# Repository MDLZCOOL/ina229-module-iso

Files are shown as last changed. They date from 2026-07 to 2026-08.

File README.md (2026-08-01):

# 电压电流模块（全隔离版）

## 简介

采用ina229前端+cs32l010f8u6单片机做的信号供电全隔离的电压电流模组，采用串口MODBUS输出，支持0-85V电压测量。



至于为什么是cs32l010f8u6，最近偶然得到几百片这个mcu，想办法用掉吧~

## 使用须知

- 支持测量的电压范围是0-85V
- 支持测量的最大电流与采样电阻有关，计算公式为`I_MAX ≤ 0.16384 / R_SHUNT`，其中R_SHUNT单位为欧姆，I单位安培
- 用户需要同时接入3.3V和5V电平，其中丝印3.3V的位置可以接入其他电平，作为串口RXTX的输出电平，5V位置只能接入5V
- “全隔离”指信号与供电全隔离，如果用户供电或信号的地与被测电流电压信号的地导通，则不隔离，但是仍可正常使用

## 上位机

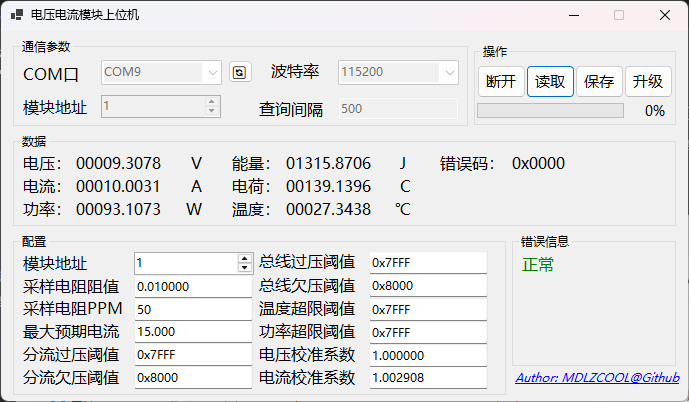
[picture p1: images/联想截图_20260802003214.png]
联想截图_20260802003214


- 上位机可以用于更改模块MODBUS地址、采样电阻信息、最大预期电流、校准系数
- 需要注意的是，最大预期电流公式见“使用须知”，并不是无限大的
- 所以用户更改采样电阻以适配不同精度，不同量程后，需要手动更新采样电阻信息，也可能需要重新设置校准系数
- 校准系数 = 实测值 ÷ 上位机显示值
- 上位机可以直接进行固件升级，连接好后，点击“升级”，选择新的bin文件即可进行升级，升级不会导致配置信息丢失。如果升级失败，可以“按住按键”并重新上电后重试

## Modbus 寄存器表

### 通信参数

| 项目 | 值 |
| --- | --- |
| 物理接口 | 串口（UART，隔离输出） |
| 协议 | Modbus RTU |
| 波特率 | 115200 bps |
| 数据位 / 校验 / 停止位 | 8 / None / 1 |
| 从机地址 | 可配置，默认 1 |
| 实现的功能码 | `0x03` 读保持寄存器、`0x06` 写单个寄存器、`0x10` 写多个寄存器 |

### 数据格式说明

- 浮点数（float）：IEEE-754 单精度，占用 2 个连续寄存器高位字在前（Big-Endian）。即地址 N 存高 16 位、地址 N+1 存低 16 位，每个寄存器内部字节大端。
- 整型（uint16）：占用 1 个寄存器，大端。
- 测量数据区为只读（RO），用于获取测量数据。
- 配置参数区为可读写（RW）：修改后先存于 RAM，需向 `0x0110` 写入保存指令才会写入 Flash。

### 保持寄存器 — 测量数据（只读）

| 地址(hex) | 地址(dec) | 寄存器范围 | 名称 | 类型(寄存器数) | 单位 | 说明 |
| --- | --- | --- | --- | --- | ---- | --- |
| 0x0000 | 0 | 0x0000–0x0001 | Voltage（电压） | float (2) | V | 总线电压 |
| 0x0002 | 2 | 0x0002–0x0003 | Current（电流） | float (2) | A | 电流 |
| 0x0004 | 4 | 0x0004–0x0005 | Power（功率） | float (2) | W | 功率 |
| 0x0006 | 6 | 0x0006–0x0007 | Charge（电荷量） | float (2) | C | 累计电荷量 |
| 0x0008 | 8 | 0x0008–0x0009 | Temperature（温度）  | float (2) | °C | 内部温度 |
| 0x000A | 10 | 0x000A–0x000B | Energy（能量） | float (2) | J | 累计能量，1 Wh = 3600 J |
| 0x000C | 12 | 0x000C | Error Code（错误码） | uint16 (1) | — | INA229 诊断/告警位域，见第 5 节 |

### 保持寄存器 — 配置参数（可读写）

| 地址(hex) | 地址(dec) | 寄存器范围 | 名称 | 类型(寄存器数) | 单位 | 默认值 | 说明 |
| --- | --- | --- | --- | --- | --- | --- | --- |
| 0x0100 | 256 | 0x0100 | ModbusAddr | uint16 (1) | — | 1 | 本机 Modbus 从机地址 |
| 0x0101 | 257 | 0x0101–0x0102 | RshuntOhm  | float (2) | Ω | 0.01 | 采样电阻值 R_SHUNT；修改后需用 0x0103 配合标定为新量程 |
| 0x0103 | 259 | 0x0103–0x0104 | IexpMax | float (2) | A | 15.0 | 最大预期电流 I_MAX；约束：`I_MAX ≤ 0.16384 / R_SHUNT`  |
| 0x0105 | 261 | 0x0105 | ShuntOVTｈ | uint16 (1) | — | 0x7FFF | 分流过压阈值（SOVL） |
| 0x0106 | 262 | 0x0106 | ShuntUVTh  | uint16 (1) | — | 0x8000 | 分流欠压阈值（SUVL） |
| 0x0107 | 263 | 0x0107 | BusOVTｈ | uint16 (1) | — | 0x7FFF | 总线过压阈值（BOVL） |
| 0x0108 | 264 | 0x0108 | BusUVTh | uint16 (1) | — | 0x8000 | 总线欠压阈值（BUVL） |
| 0x0109 | 265 | 0x0109 | TempOLTh | uint16 (1) | — | 0x7FFF | 温度超限阈值（TEMP_LIMIT） |
| 0x010A | 266 | 0x010A | PowerOLTh  | uint16 (1) | — | 0x7FFF | 功率超限阈值（PWR_LIMIT） |
| 0x010B | 267 | 0x010B–0x010C | VoltageK | float (2) | — | 1.0 | 电压校准系数 = `实测值 ÷ 显示值` |
| 0x010D | 269 | 0x010D–0x010E | CurrentK | float (2) | — | 1.0 | 电流校准系数 = `实测值 ÷ 显示值` |
| 0x010F | 271 | 0x010F | RshuntPPM  | uint16 (1) | ppm/°C | 50 | 采样电阻温度系数 |
| 0x0110 | 272 | 0x0110 | SaveCmd | uint16 (1) | — | 0 | 写命令：写入 `0x4B56` 将当前配置保存到 Flash |
| 0x0111 | 273 | 0x0111 | BootCmd | uint16 (1) | — | 0 | 写命令：写入 `0x4B4F` 重启进入固件升级模式 |

### 错误码（Error Code，0x000C）位定义

| Bit  | 宏 / 名称 | 含义 |
| ---- | --- | --- |
| 0 | MEMSTAT | 存储器校验错误 |
| 1 | CNVRF | 转换完成标志 |
| 2 | POL | 功率超限 |
| 3 | BUSUL | 总线欠压 |
| 4 | BUSOL | 总线过压 |
| 5 | SHNTUL | 分流欠压 |
| 6 | SHNTOL | 分流过压 |
| 7 | TMPOL | 温度超限 |
| 8 | OFFLINE | 芯片离线 |
| 9 | MATHOF | 数学计算溢出 |
| 10 | CHARGEOF  | 电荷寄存器溢出 |
| 11 | ENERGYOF  | 能量寄存器溢出 |

### 使用要点

- 读实时数据：用功能码 `0x03` 读取 0x0000–0x000C。
- 改配置并保存：先写 0x0100–0x010F 中目标寄存器，再向 0x0110 写 `0x4B56` 保存。
- 固件升级：向 0x0111 写 `0x4B4F` 进入升级模式，再用 YMODEM 方式烧录新 bin。
- 校准：`校准系数 = 实测值 ÷ 上位机显示值`，写入电压电流校准系数后保存。
- 量程约束：更换采样电阻后需重设采样电阻信息与最大预期电流，并满足 `I_MAX ≤ 0.16384 / R_SHUNT`，必要时重新校准系数。

## 目录结构

- [./Hardware](Hardware)下为硬件设计，使用Kicad 8.0以上版本打开
- [./Firmware](Firmware)下为编译好的固件
- [./Software](Software)下为mcu源码
- [./Upper](Upper)下为上位机源码
- [./Document](Document)下为mcu的ds和pack

## Changelog

20260713更新：初始化仓库。硬件完成，软件还没写，已送去jlc打样pcb+smt。。希望这个究极灵车mcu不要翻车了

20260801更新：V1.0，完成上位机，上位机实现了数据测量、参数修改、固件更新。完成下位机Application+Bootloader，实现modbus通信，传感器读取，参数保存，固件更新。

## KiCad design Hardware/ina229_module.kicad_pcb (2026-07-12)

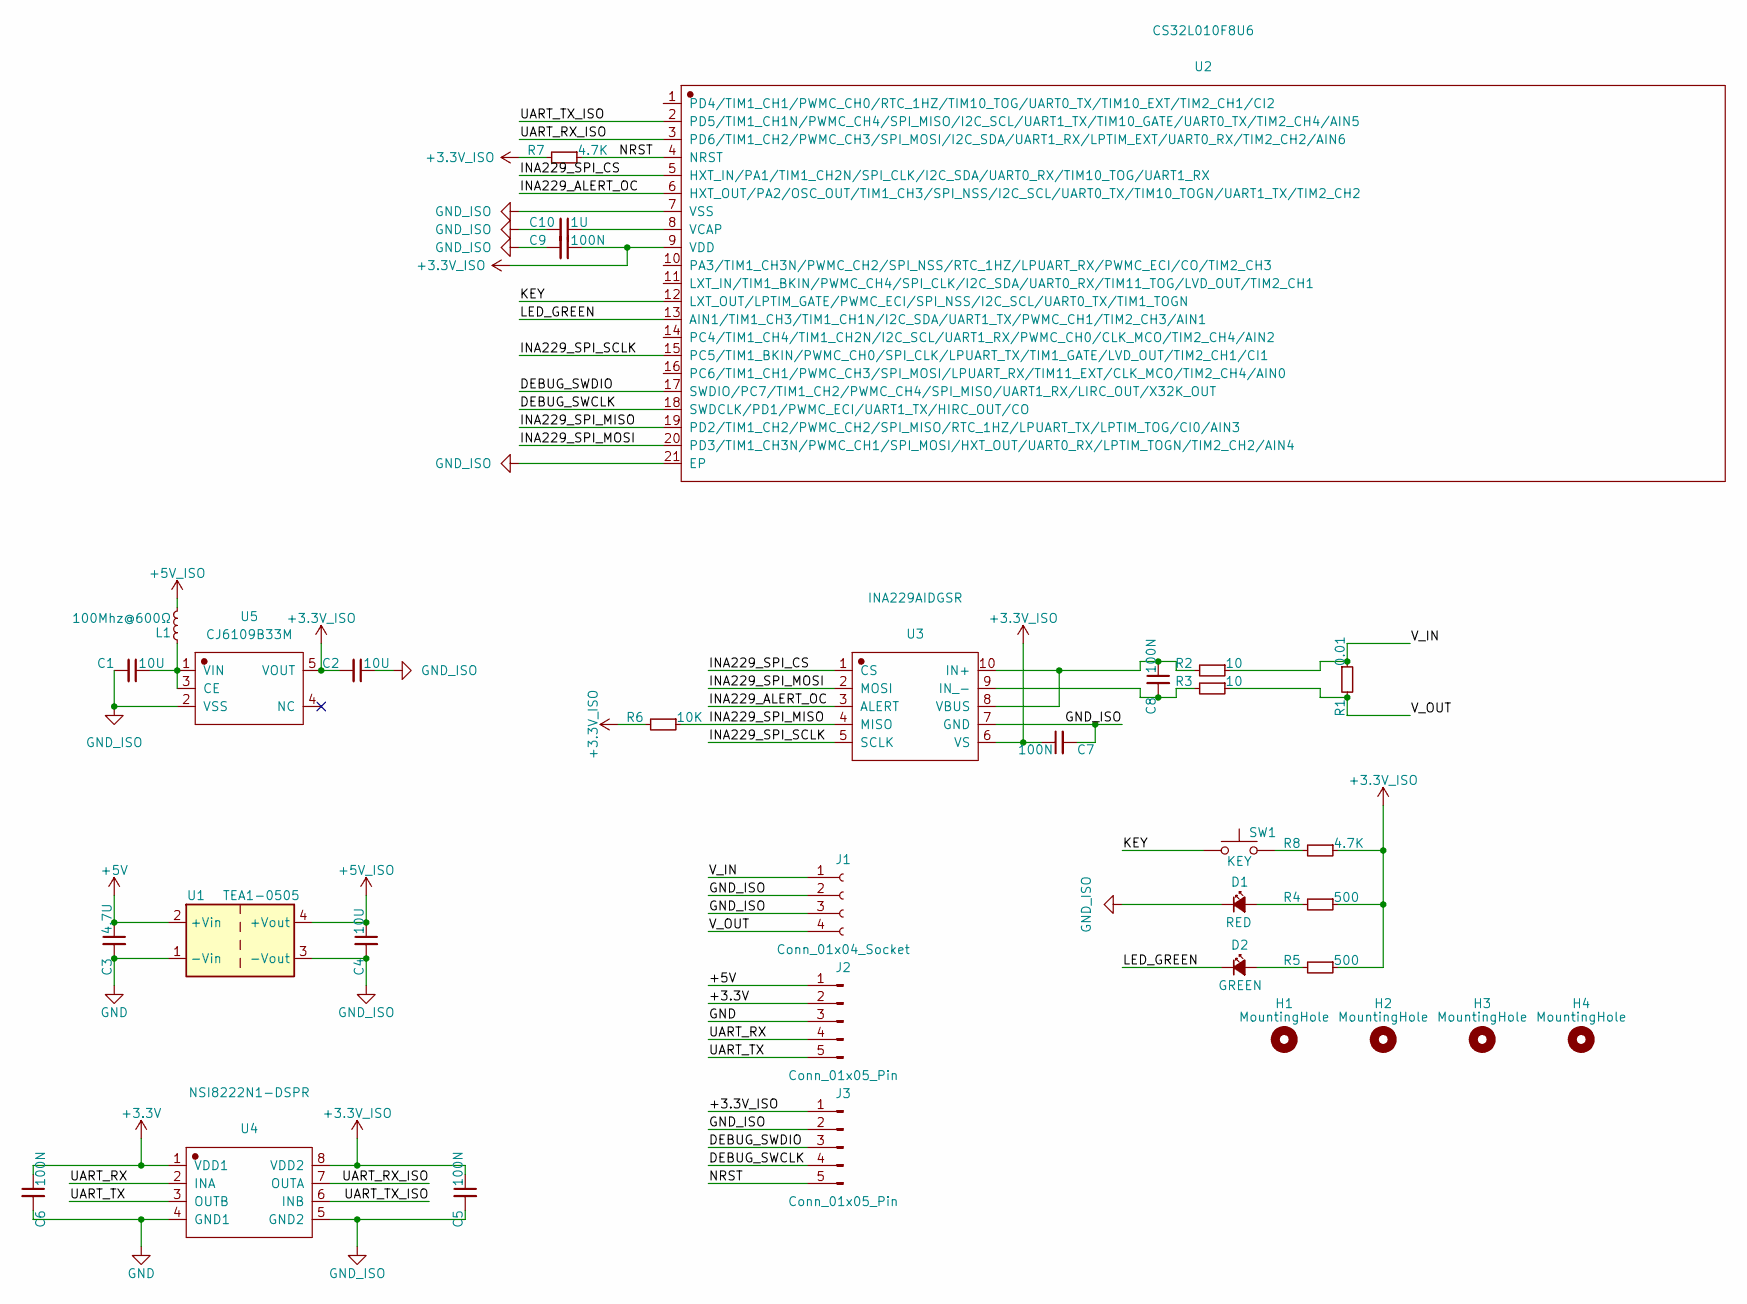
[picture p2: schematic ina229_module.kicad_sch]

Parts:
C1, C2, C4: 10U; C_0603_1608Metric_Pad1.08x0.95mm_HandSolder
C3: 4.7U; C_0603_1608Metric_Pad1.08x0.95mm_HandSolder
C5, C6, C7, C8, C9: 100N; C_0603_1608Metric_Pad1.08x0.95mm_HandSolder
C10: 1U; C_0603_1608Metric_Pad1.08x0.95mm_HandSolder
D1: RED; LED_0603_1608Metric_Pad1.05x0.95mm_HandSolder
D2: GREEN; LED_0603_1608Metric_Pad1.05x0.95mm_HandSolder
H1, H2, H3, H4: MountingHole; MountingHole_3.2mm_M3_ISO7380
J1: Conn_01x04_Socket; TerminalBlock_Phoenix_MKDS-1,5-4-5.08_1x04_P5.08mm_Horizont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
J2: Conn_01x05_Pin; JST_XH_B5B-XH-A_1x05_P2.50mm_Vertical
J3: Conn_01x05_Pin; PinHeader_1x05_P2.54mm_Vertical
L1: 100Mhz@600Ω; L_0603_1608Metric_Pad1.05x0.95mm_HandSolder
R1: 0.01; R_2512_6332Metric_Pad1.40x3.35mm_HandSolder
R2, R3: 10; R_0603_1608Metric_Pad0.98x0.95mm_HandSolder
R4, R5: 500; R_0603_1608Metric_Pad0.98x0.95mm_HandSolder
R6: 10K; R_0603_1608Metric_Pad0.98x0.95mm_HandSolder
R7, R8: 4.7K; R_0603_1608Metric_Pad0.98x0.95mm_HandSolder
SW1: KEY; SW_SPST_B3U-1000P
U1: TEA1-0505; Converter_DCDC_TRACO_TEA1-xxxx_THT
U2: CS32L010F8U6; WFQFN-20_L3.0-W3.0-P0.40-TL-EP1.7
U3: INA229AIDGSR; VSSOP-10_L3.0-W3.0-P0.50-LS4.9-BL
U4: NSI8222N1-DSPR; SOP-8_L4.9-W3.9-P1.27-LS6.0-BL
U5: CJ6109B33M; SOT-23-5_L2.9-W1.6-P0.95-LS2.8-BR

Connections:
+3.3V: C6.1, J2.2, U4.1 (VDD1)
+3.3V_ISO: C2.2, C5.1, C7.1, C9.1, J3.1, R4.1, R5.1, R6.2, R7.2, R8.1, U2.9 (VDD), U3.6 (VS), U4.8 (VDD2), U5.5 (VOUT)
+5V: C3.1, J2.1, U1.2 (+Vin)
+5V_ISO: C4.1, L1.2, U1.4 (+Vout)
/DEBUG_SWCLK: J3.4, U2.18 (SWDCLK/PD1/PWMC_ECI/UART1_TX/HIRC_OUT/CO)
/DEBUG_SWDIO: J3.3, U2.17 (SWDIO/PC7/TIM1_CH2/PWMC_CH4/SPI_MISO/UA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)
/INA229_ALERT_OC: U2.6 (HXT_OUT/PA2/OSC_OUT/TIM1_CH3/SPI_NSS/I2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), U3.3 (ALERT)
/INA229_SPI_CS: U2.5 (HXT_IN/PA1/TIM1_CH2N/SPI_CLK/I2C_SDA/UA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), U3.1 (CS)
/INA229_SPI_MISO: R6.1, U2.19 (PD2/TIM1_CH2/PWMC_CH2/SPI_MISO/RTC_1HZ/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), U3.4 (MISO)
/INA229_SPI_MOSI: U2.20 (PD3/TIM1_CH3N/PWMC_CH1/SPI_MOSI/HXT_OUT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), U3.2 (MOSI)
/INA229_SPI_SCLK: U2.15 (PC5/TIM1_BKIN/PWMC_CH0/SPI_CLK/LPUART_T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), U3.5 (SCLK)
/KEY: SW1.1, U2.12 (LXT_OUT/LPTIM_GATE/PWMC_ECI/SPI_NSS/I2C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)
/LED_GREEN: D2.1 (K), U2.13 (AIN1/TIM1_CH3/TIM1_CH1N/I2C_SDA/UART1_T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)
/NRST: J3.5, R7.1, U2.4 (NRST)
/UART_RX: J2.4, U4.2 (INA)
/UART_RX_ISO: U2.3 (PD6/TIM1_CH2/PWMC_CH3/SPI_MOSI/I2C_SDA/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), U4.7 (OUTA)
/UART_TX: J2.5, U4.3 (OUTB)
/UART_TX_ISO: U2.2 (PD5/TIM1_CH1N/PWMC_CH4/SPI_MISO/I2C_SCL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), U4.6 (INB)
/V_IN: J1.1, R1.1, R2.1
/V_OUT: J1.4, R1.2, R3.1
GND: C3.2, C6.2, J2.3, U1.1 (-Vin), U4.4 (GND1)
GND_ISO: C1.2, C2.1, C4.2, C5.2, C7.2, C9.2, C10.2, D1.1 (K), J1.2, J1.3, J3.2, U1.3 (-Vout), U2.7 (VSS), U2.21 (EP), U3.7 (GND), U4.5 (GND2), U5.2 (VSS)
unnamed: D1.2 (A), R4.2
unnamed: D2.2 (A), R5.2
unnamed: R8.2, SW1.2
unnamed: C10.1, U2.8 (VCAP)
unnamed: C8.1, R2.2, U3.8 (VBUS), U3.10 (IN+)
unnamed: C8.2, R3.2, U3.9 (IN_-)
unnamed: C1.1, L1.1, U5.1 (VIN), U5.3 (CE)

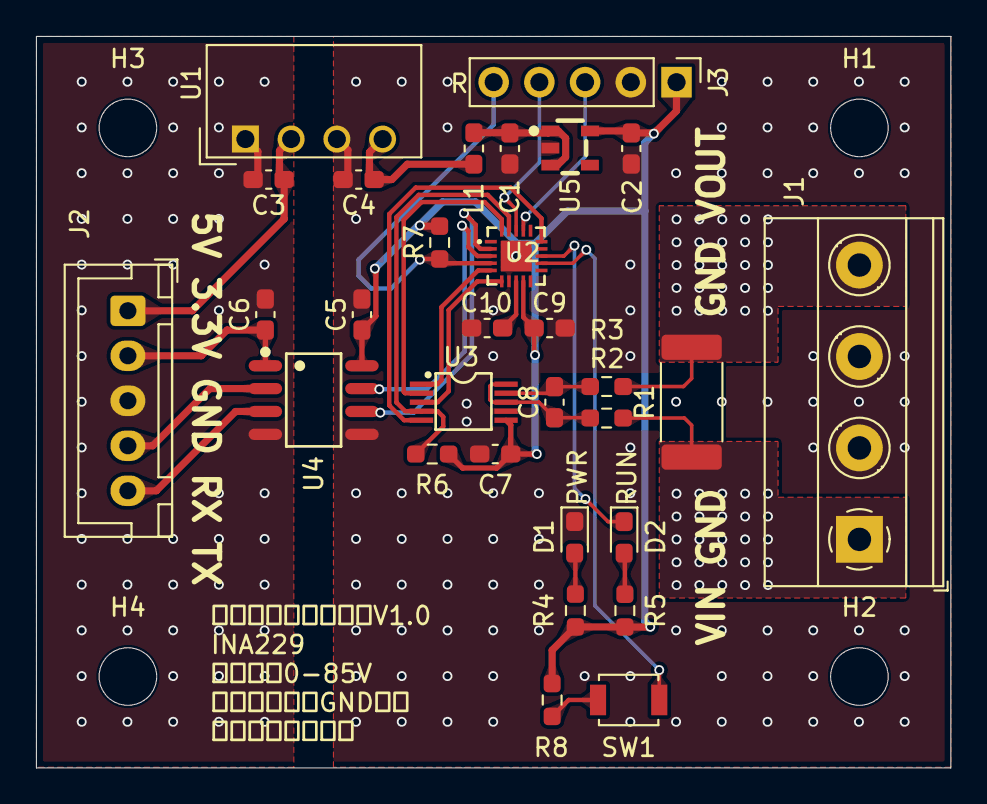
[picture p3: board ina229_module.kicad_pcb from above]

Board: 2 copper layers, 50.8 x 40.6 mm, 34 parts (0 on the bottom side), 29 nets.

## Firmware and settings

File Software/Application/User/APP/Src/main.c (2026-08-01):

/*
 * SPDX-FileCopyrightText: 2026 MDLZCOOL <mdlzcool@foxmail.com>
 *
 * SPDX-License-Identifier: Apache-2.0
 */

#include "main.h"

#include "app_kv.h"
#include "app_modbus.h"
#include "bsp_ina229.h"
#include "bsp_led.h"
#include "bsp_uart_fifo.h"
#include "perf_counter.h"
#include "soft_timer.h"

ina229_data_t g_ina229_data_inst;

CONFIG_T g_config;
int g_config_flash_valid = 0;

/* 加载默认值 */
static void config_load_defaults(void) {
  g_config.modbus_addr = CFG_DEFAULT_MODBUS_ADDR;
  g_config.rshunt_ohm = CFG_DEFAULT_RSHUNT_OHM;
  g_config.iexp_max = CFG_DEFAULT_IEXP_MAX;
  g_config.shunt_over_voltage_th = CFG_DEFAULT_SHUNT_OVER_VOLTAGE_TH;
  g_config.shunt_under_voltage_th = CFG_DEFAULT_SHUNT_UNDER_VOLTAGE_TH;
  g_config.bus_over_voltage_th = CFG_DEFAULT_BUS_OVER_VOLTAGE_TH;
  g_config.bus_under_voltage_th = CFG_DEFAULT_BUS_UNDER_VOLTAGE_TH;
  g_config.temp_over_limit_th = CFG_DEFAULT_TEMP_OVER_LIMIT_TH;
  g_config.power_over_limit_th = CFG_DEFAULT_POWER_OVER_LIMIT_TH;
  g_config.voltage_k = CFG_DEFAULT_VOLTAGE_K;
  g_config.current_k = CFG_DEFAULT_CURRENT_K;
  g_config.rshunt_ppm = CFG_DEFAULT_RSHUNT_PPM;
}

static void config_load_from_flash(void) {
  int ok = 0;
  ok += (app_KV_GetInt("1", &g_config.modbus_addr) == KV_OK);
  ok += (app_KV_GetFloat("2", &g_config.rshunt_ohm) == KV_OK);
  ok += (app_KV_GetFloat("3", &g_config.iexp_max) == KV_OK);
  ok += (app_KV_GetUint16("4", &g_config.shunt_over_voltage_th) == KV_OK);
  ok += (app_KV_GetUint16("5", &g_config.shunt_under_voltage_th) == KV_OK);
  ok += (app_KV_GetUint16("6", &g_config.bus_over_voltage_th) == KV_OK);
  ok += (app_KV_GetUint16("7", &g_config.bus_under_voltage_th) == KV_OK);
  ok += (app_KV_GetUint16("8", &g_config.temp_over_limit_th) == KV_OK);
  ok += (app_KV_GetUint16("9", &g_config.power_over_limit_th) == KV_OK);
  ok += (app_KV_GetFloat("10", &g_config.voltage_k) == KV_OK);
  ok += (app_KV_GetFloat("11", &g_config.current_k) == KV_OK);
  ok += (app_KV_GetUint16("12", &g_config.rshunt_ppm) == KV_OK);

  /* 参数全部读到才算有效 */
  if (ok == 12) {
    g_config_flash_valid = 1;
    LOG_printf("Loaded from Flash.\r\n");
  } else {
    LOG_printf("Flash incomplete, using defaults.\r\n");
  }
}

/* 首次烧录写入默认值 */
static void config_save_defaults_to_flash(void) {
  app_KV_SetInt("1", g_config.modbus_addr);
  app_KV_SetFloat("2", g_config.rshunt_ohm);
  app_KV_SetFloat("3", g_config.iexp_max);
  app_KV_SetUint16("4", g_config.shunt_over_voltage_th);
  app_KV_SetUint16("5", g_config.shunt_under_voltage_th);
  app_KV_SetUint16("6", g_config.bus_over_voltage_th);
  app_KV_SetUint16("7", g_config.bus_under_voltage_th);
  app_KV_SetUint16("8", g_config.temp_over_limit_th);
  app_KV_SetUint16("9", g_config.power_over_limit_th);
  app_KV_SetFloat("10", g_config.voltage_k);
  app_KV_SetFloat("11", g_config.current_k);
  app_KV_SetUint16("12", g_config.rshunt_ppm);

  app_KV_Save();
  LOG_printf("Defaults saved to Flash.\r\n");
}

// 24M clock
void SystemClock_Config(void) {
  RCC_OscInitTypeDef RCC_OscInitStruct = {0};
  RCC_ClkInitTypeDef RCC_ClkInitStruct = {0};

  RCC_OscInitStruct.OscillatorType = RCC_OSCILLATORTYPE_HIRC;
  RCC_OscInitStruct.HIRCState = RCC_HIRC_ON;
  RCC_OscInitStruct.HIRCCalibrationValue = RCC_HIRCCALIBRATION_24M;

  if (HAL_RCC_OscConfig(&RCC_OscInitStruct) != HAL_OK) {
    Error_Handler();
  }

  RCC_ClkInitStruct.ClockType =
      RCC_CLOCKTYPE_HCLK | RCC_CLOCKTYPE_SYSCLK | RCC_CLOCKTYPE_PCLK;
  RCC_ClkInitStruct.SYSCLKSource = RCC_SYSCLKSOURCE_HIRC;
  RCC_ClkInitStruct.AHBCLKDivider = RCC_HCLK_DIV1;
  RCC_ClkInitStruct.APBCLKDivider = RCC_PCLK_DIV1;

  if (HAL_RCC_ClockConfig(&RCC_ClkInitStruct) != HAL_OK) {
    Error_Handler();
  }
}

#define APP_ADDR 0x00002000

int main(void) {
  /* 硬件复位后 PRIMASK=0；若从 Bootloader 跳转来，确保中断开启 */
  __enable_irq();

  HAL_Init();

  SystemClock_Config();

#if DEBUG_RTT
  SEGGER_RTT_Init();
#endif

  app_KV_Init();
  app_KV_List();

  config_load_defaults();

  config_load_from_flash();

  if (!g_config_flash_valid) {
    config_save_defaults_to_flash();
  }

  LOG_printf("modbus addr=%d\r\n", g_config.modbus_addr);
  LOG_printf("rshunt %d.%03d Ohm, Imax=%d.%03d A\r\n",
             FLOAT_INT(g_config.rshunt_ohm), FLOAT_FRAC3(g_config.rshunt_ohm),
             FLOAT_INT(g_config.iexp_max), FLOAT_FRAC3(g_config.iexp_max));

  bsp_InitLed();

  bsp_InitIna229(g_config.rshunt_ohm, g_config.iexp_max);

  INA229_SetShuntTemperatureCoefficient(g_config.rshunt_ppm);
  INA229_SetTemperatureCompensation(1);

  INA229_SetAverage(INA229_ADC_CONFIG_AVG_64);
  INA229_SetShuntOvervoltageTH(g_config.shunt_over_voltage_th);
  INA229_SetShuntUndervoltageTH(g_config.shunt_under_voltage_th);
  INA229_SetBusOvervoltageTH(g_config.bus_over_voltage_th);
  INA229_SetBusUndervoltageTH(g_config.bus_under_voltage_th);
  INA229_SetTemperatureOverLimitTH(g_config.temp_over_limit_th);
  INA229_SetPowerOverLimitTH(g_config.power_over_limit_th);

  bsp_InitUart();

  app_ModbusInit(g_config.modbus_addr);
  app_Modbus_ConfigInit();

  InitSoftTimer();
  StartSoftAutoTimer(0, 1);
  StartSoftAutoTimer(1, 10);
  StartSoftAutoTimer(2, 500);

  while (1) {
    if (CheckSoftTimer(0) == 1) {
      app_Modbus_Poll();
    }
    if (CheckSoftTimer(1) == 1) {
      int32_t cycle_used = 0;
      double t = INA229_GetShuntVoltage();
      // LOG_printf("%d.%06d V\r\n", FLOAT_INT(t), FLOAT_FRAC6(t));
      __cycleof__("", { cycle_used = _; }) {
        g_ina229_data_inst.voltage =
            INA229_GetBusVoltage() * g_config.voltage_k;
        g_ina229_data_inst.current = INA229_GetCurrent() * g_config.current_k;
        g_ina229_data_inst.temp = INA229_GetTemperature();
        g_ina229_data_inst.charge = INA229_GetCharge();
        g_ina229_data_inst.power =
            INA229_GetPower() * g_config.current_k * g_config.voltage_k;
        g_ina229_data_inst.energy = INA229_GetEnergy();
        g_ina229_data_inst.err_code = INA229_Get_ErrorCode();
        Modbus_Update_INA229(&g_ina229_data_inst);
      }

      // LOG_printf("Task: %d cycles, approx %d us\r\n", cycle_used, cycle_used
      // / 24);
    }
    if (CheckSoftTimer(2) == 1) {
      bsp_LedToggle(1);
    }
  }
}

void Error_Handler(void) {}

#ifdef USE_FULL_ASSERT
void assert_failed(uint8_t *file, uint32_t line) {}
#endif /* USE_FULL_ASSERT */

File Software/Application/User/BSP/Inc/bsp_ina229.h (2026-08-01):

/*
 * SPDX-FileCopyrightText: 2026 MDLZCOOL <mdlzcool@foxmail.com>
 *
 * SPDX-License-Identifier: Apache-2.0
 */

#ifndef __BSP_INA229_H
#define __BSP_INA229_H

#ifdef __cplusplus
extern "C" {
#endif

#include <stdint.h>

#include "main.h"

#define INA229_CURRENT_LSB_DENOM (524288.0f)

/* INA229 register map (Table 7-3) */
#define INA229_REG_CONFIG 0x00U
#define INA229_REG_ADC_CONFIG 0x01U
#define INA229_REG_SHUNT_CAL 0x02U
#define INA229_REG_SHUNT_TEMPCO 0x03U
#define INA229_REG_VSHUNT 0x04U
#define INA229_REG_VBUS 0x05U
#define INA229_REG_DIETEMP 0x06U
#define INA229_REG_CURRENT 0x07U
#define INA229_REG_POWER 0x08U
#define INA229_REG_ENERGY 0x09U
#define INA229_REG_CHARGE 0x0AU
#define INA229_REG_DIAG_ALRT 0x0BU
#define INA229_REG_SOVL 0x0CU
#define INA229_REG_SUVL 0x0DU
#define INA229_REG_BOVL 0x0EU
#define INA229_REG_BUVL 0x0FU
#define INA229_REG_TEMP_LIMIT 0x10U
#define INA229_REG_PWR_LIMIT 0x11U
#define INA229_REG_MANUFACTURER_ID 0x3EU
#define INA229_REG_DEVICE_ID 0x3FU

/* CONFIG register fields */
#define INA229_CONFIG_RST_Pos 15U
#define INA229_CONFIG_RST_Msk (0x1U << INA229_CONFIG_RST_Pos)
#define INA229_CONFIG_RST INA229_CONFIG_RST_Msk
#define INA229_CONFIG_RSTACC_Pos 14U
#define INA229_CONFIG_RSTACC_Msk (0x1U << INA229_CONFIG_RSTACC_Pos)
#define INA229_CONFIG_RSTACC INA229_CONFIG_RSTACC_Msk
#define INA229_CONFIG_CONVDLY_Pos 6U
#define INA229_CONFIG_CONVDLY_Msk (0xFFU << INA229_CONFIG_CONVDLY_Pos)
#define INA229_CONFIG_TEMPCOMP_Pos 5U
#define INA229_CONFIG_TEMPCOMP_Msk (0x1U << INA229_CONFIG_TEMPCOMP_Pos)
#define INA229_CONFIG_TEMPCOMP INA229_CONFIG_TEMPCOMP_Msk
#define INA229_CONFIG_ADCRANGE_Pos 4U
#define INA229_CONFIG_ADCRANGE_Msk (0x1U << INA229_CONFIG_ADCRANGE_Pos)
#define INA229_CONFIG_ADCRANGE_163mV (0x0U << INA229_CONFIG_ADCRANGE_Pos)
#define INA229_CONFIG_ADCRANGE_40mV (0x1U << INA229_CONFIG_ADCRANGE_Pos)

/* ADC_CONFIG register fields */
#define INA229_ADC_CONFIG_MODE_Pos 12U
#define INA229_ADC_CONFIG_MODE_Msk (0xFU << INA229_ADC_CONFIG_MODE_Pos)
#define INA229_ADC_CONFIG_MODE_SHUTDOWN (0x0U << INA229_ADC_CONFIG_MODE_Pos)
#define INA229_ADC_CONFIG_MODE_TRIG_BUS (0x1U << INA229_ADC_CONFIG_MODE_Pos)
#define INA229_ADC_CONFIG_MODE_TRIG_SHUNT (0x2U << INA229_ADC_CONFIG_MODE_Pos)
#define INA229_ADC_CONFIG_MODE_TRIG_SHUNT_BUS \
  (0x3U << INA229_ADC_CONFIG_MODE_Pos)
#define INA229_ADC_CONFIG_MODE_TRIG_TEMP (0x4U << INA229_ADC_CONFIG_MODE_Pos)
#define INA229_ADC_CONFIG_MODE_TRIG_TEMP_BUS \
  (0x5U << INA229_ADC_CONFIG_MODE_Pos)
#define INA229_ADC_CONFIG_MODE_TRIG_TEMP_SHUNT \
  (0x6U << INA229_ADC_CONFIG_MODE_Pos)
#define INA229_ADC_CONFIG_MODE_TRIG_BUS_SHUNT_TEMP \
  (0x7U << INA229_ADC_CONFIG_MODE_Pos)
#define INA229_ADC_CONFIG_MODE_SHUTDOWN_ALT (0x8U << INA229_ADC_CONFIG_MODE_Pos)
#define INA229_ADC_CONFIG_MODE_CONT_BUS (0x9U << INA229_ADC_CONFIG_MODE_Pos)
#define INA229_ADC_CONFIG_MODE_CONT_SHUNT (0xAU << INA229_ADC_CONFIG_MODE_Pos)
#define INA229_ADC_CONFIG_MODE_CONT_SHUNT_BUS \
  (0xBU << INA229_ADC_CONFIG_MODE_Pos)
#define INA229_ADC_CONFIG_MODE_CONT_TEMP (0xCU << INA229_ADC_CONFIG_MODE_Pos)
#define INA229_ADC_CONFIG_MODE_CONT_BUS_TEMP \
  (0xDU << INA229_ADC_CONFIG_MODE_Pos)
#define INA229_ADC_CONFIG_MODE_CONT_TEMP_SHUNT \
  (0xEU << INA229_ADC_CONFIG_MODE_Pos)
#define INA229_ADC_CONFIG_MODE_CONT_BUS_SHUNT_TEMP \
  (0xFU << INA229_ADC_CONFIG_MODE_Pos)

#define INA229_ADC_CONFIG_VBUSCT_Pos 9U
#define INA229_ADC_CONFIG_VBUSCT_Msk (0x7U << INA229_ADC_CONFIG_VBUSCT_Pos)
#define INA229_ADC_CONFIG_VBUSCT_50US (0x0U << INA229_ADC_CONFIG_VBUSCT_Pos)
#define INA229_ADC_CONFIG_VBUSCT_84US (0x1U << INA229_ADC_CONFIG_VBUSCT_Pos)
#define INA229_ADC_CONFIG_VBUSCT_150US (0x2U << INA229_ADC_CONFIG_VBUSCT_Pos)
#define INA229_ADC_CONFIG_VBUSCT_280US (0x3U << INA229_ADC_CONFIG_VBUSCT_Pos)
#define INA229_ADC_CONFIG_VBUSCT_540US (0x4U << INA229_ADC_CONFIG_VBUSCT_Pos)
#define INA229_ADC_CONFIG_VBUSCT_1052US (0x5U << INA229_ADC_CONFIG_VBUSCT_Pos)
#define INA229_ADC_CONFIG_VBUSCT_2074US (0x6U << INA229_ADC_CONFIG_VBUSCT_Pos)
#define INA229_ADC_CONFIG_VBUSCT_4120US (0x7U << INA229_ADC_CONFIG_VBUSCT_Pos)

#define INA229_ADC_CONFIG_VSHCT_Pos 6U
#define INA229_ADC_CONFIG_VSHCT_Msk (0x7U << INA229_ADC_CONFIG_VSHCT_Pos)
#define INA229_ADC_CONFIG_VSHCT_50US (0x0U << INA229_ADC_CONFIG_VSHCT_Pos)
#define INA229_ADC_CONFIG_VSHCT_84US (0x1U << INA229_ADC_CONFIG_VSHCT_Pos)
#define INA229_ADC_CONFIG_VSHCT_150US (0x2U << INA229_ADC_CONFIG_VSHCT_Pos)
#define INA229_ADC_CONFIG_VSHCT_280US (0x3U << INA229_ADC_CONFIG_VSHCT_Pos)
#define INA229_ADC_CONFIG_VSHCT_540US (0x4U << INA229_ADC_CONFIG_VSHCT_Pos)
#define INA229_ADC_CONFIG_VSHCT_1052US (0x5U << INA229_ADC_CONFIG_VSHCT_Pos)
#define INA229_ADC_CONFIG_VSHCT_2074US (0x6U << INA229_ADC_CONFIG_VSHCT_Pos)
#define INA229_ADC_CONFIG_VSHCT_4120US (0x7U << INA229_ADC_CONFIG_VSHCT_Pos)

#define INA229_ADC_CONFIG_VTCT_Pos 3U
#define INA229_ADC_CONFIG_VTCT_Msk (0x7U << INA229_ADC_CONFIG_VTCT_Pos)
#define INA229_ADC_CONFIG_VTCT_50US (0x0U << INA229_ADC_CONFIG_VTCT_Pos)
#define INA229_ADC_CONFIG_VTCT_84US (0x1U << INA229_ADC_CONFIG_VTCT_Pos)
#define INA229_ADC_CONFIG_VTCT_150US (0x2U << INA229_ADC_CONFIG_VTCT_Pos)
#define INA229_ADC_CONFIG_VTCT_280US (0x3U << INA229_ADC_CONFIG_VTCT_Pos)
#define INA229_ADC_CONFIG_VTCT_540US (0x4U << INA229_ADC_CONFIG_VTCT_Pos)
#define INA229_ADC_CONFIG_VTCT_1052US (0x5U << INA229_ADC_CONFIG_VTCT_Pos)
#define INA229_ADC_CONFIG_VTCT_2074US (0x6U << INA229_ADC_CONFIG_VTCT_Pos)
#define INA229_ADC_CONFIG_VTCT_4120US (0x7U << INA229_ADC_CONFIG_VTCT_Pos)

#define INA229_ADC_CONFIG_AVG_Pos 0U
#define INA229_ADC_CONFIG_AVG_Msk (0x7U << INA229_ADC_CONFIG_AVG_Pos)
#define INA229_ADC_CONFIG_AVG_1 (0x0U << INA229_ADC_CONFIG_AVG_Pos)
#define INA229_ADC_CONFIG_AVG_4 (0x1U << INA229_ADC_CONFIG_AVG_Pos)
#define INA229_ADC_CONFIG_AVG_16 (0x2U << INA229_ADC_CONFIG_AVG_Pos)
#define INA229_ADC_CONFIG_AVG_64 (0x3U << INA229_ADC_CONFIG_AVG_Pos)
#define INA229_ADC_CONFIG_AVG_128 (0x4U << INA229_ADC_CONFIG_AVG_Pos)
#define INA229_ADC_CONFIG_AVG_256 (0x5U << INA229_ADC_CONFIG_AVG_Pos)
#define INA229_ADC_CONFIG_AVG_512 (0x6U << INA229_ADC_CONFIG_AVG_Pos)
#define INA229_ADC_CONFIG_AVG_1024 (0x7U << INA229_ADC_CONFIG_AVG_Pos)

typedef enum {
  INA229_ERR_NONE = 0x0000U,
  INA229_ERR_MEMSTAT = (1U << 0),    // Bit  0: 存储器校验
  INA229_ERR_CNVRF = (1U << 1),      // Bit  1: 转换完成标志
  INA229_ERR_POL = (1U << 2),        // Bit  2: 功率超限
  INA229_ERR_BUSUL = (1U << 3),      // Bit  3: 总线欠压
  INA229_ERR_BUSOL = (1U << 4),      // Bit  4: 总线过压
  INA229_ERR_SHNTUL = (1U << 5),     // Bit  5: 分流欠压
  INA229_ERR_SHNTOL = (1U << 6),     // Bit  6: 分流过压
  INA229_ERR_TMPOL = (1U << 7),      // Bit  7: 温度超限
  INA229_ERR_OFFLINE = (1U << 8),    // Bit  8: 芯片离线
  INA229_ERR_MATHOF = (1U << 9),     // Bit  9: 数学计算溢出
  INA229_ERR_CHARGEOF = (1U << 10),  // Bit 10: 电荷寄存器溢出
  INA229_ERR_ENERGYOF = (1U << 11),  // Bit 11: 能量寄存器溢出
} INA229_Error_t;
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
